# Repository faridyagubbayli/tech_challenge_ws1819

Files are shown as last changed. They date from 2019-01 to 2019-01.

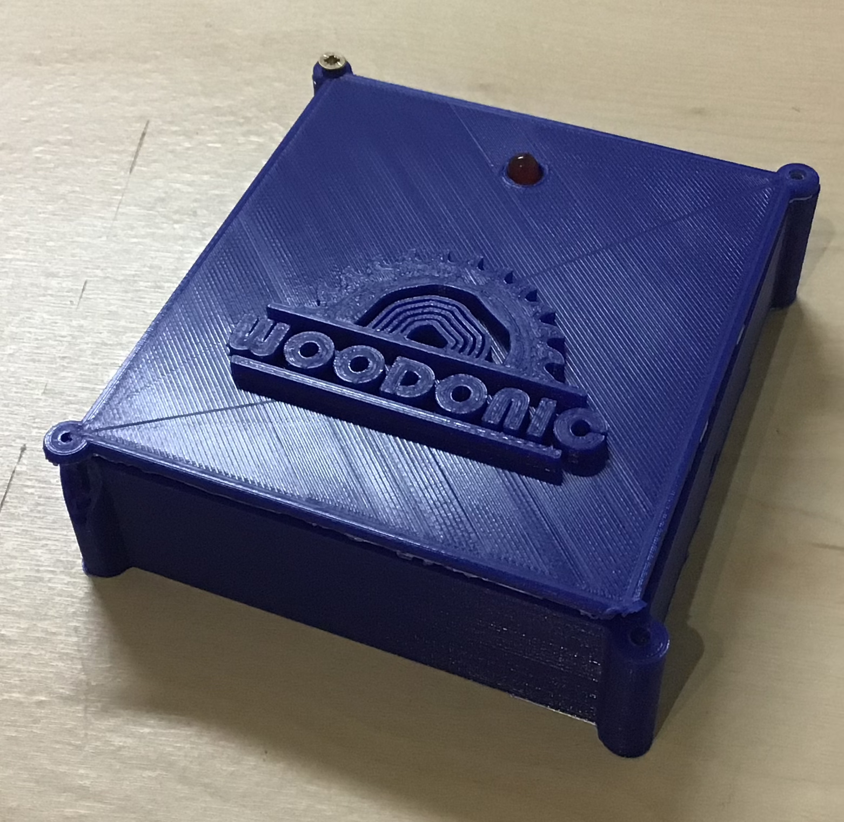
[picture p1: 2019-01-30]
IMG_0543.jpg

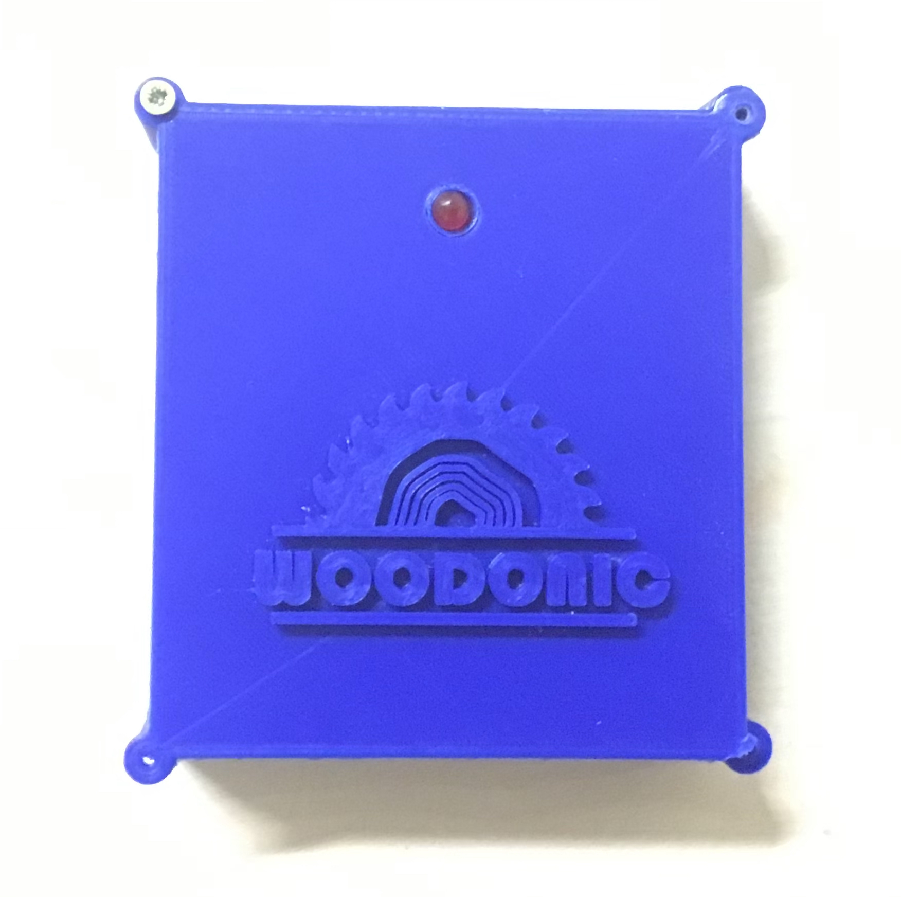
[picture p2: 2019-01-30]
IMG_3845.jpg

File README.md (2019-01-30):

# TUM Tech Challenge WS18_19 | Team AzTech - Woodonic | MakerSpace Challenge

This repository consists of following files:
- Unsupervised Audio Anomaly Detection with Gaussian Mixture Model  => Code for developing Machine Learning Solution
- Training ML for Raspberry PI.ipynb => Code for preparing Machine Learning Model for Raspberry Pi
- Raspberry_Pi_code.py => Code thats meant to be run inside Raspberry Pi, loads trained model and processes audio signals
- WOODONIC.pdf => Technical Documentation
- saved_models/ folder => Contains trained Machine Learning Folders

Additionally, you can find audio recording dataset and 3D design of the prototype in the following link (not uploaded here due to GitHub filesize limits):

https://drive.google.com/drive/folders/1RtNK6KFaf1NV8bzQA8amQgyWZAyrzATF?usp=sharing

Note that these dataset is required for running the code. Please download it to the main directory of the project such that all three folders stay at the main directory.

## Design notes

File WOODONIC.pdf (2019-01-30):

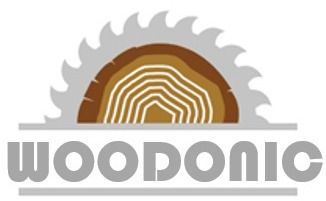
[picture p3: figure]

# Technical Documentation

## WOODONIC is a device that detects abnormal sounds in the cutting process of a table

saw and warns users with the notification light to stop the process.

# Hardware Components

Raspberry Pi Zero | x1

## Used for processing input audio signals and running trained Machine

Learning Model in order to predict anomalies.

16 GB MicroSD card | x1

## Used to install Raspbian OS on the Raspberry Pi Zero and store the solution code

USB mini microphone | x1

## Used for capturing audio input

MPU 6050 Accelerometer and Gyroscope sensor | x1

## Used to predict whether machine is working or not. Takes role in

Power Saving feature.

Light Emitting Diode | x1
User is notified by LED blink.
L7805 9V to 5V Voltage Regulator | x1

## Used to downgrade voltage from power source to be compatible with Raspberry Pi

## Woodonic by AzTech | Tech Challenge WS1819 | MakerSpace

# Software apps and Services

## Jupyter Notebooks Used while developing software solution in PC

## Raspbian OS Used to power up Raspberry PI Zero

## Scikit Sklearn Machine Learning Part is implemented using this Python Library

# Connecting Hardware Parts

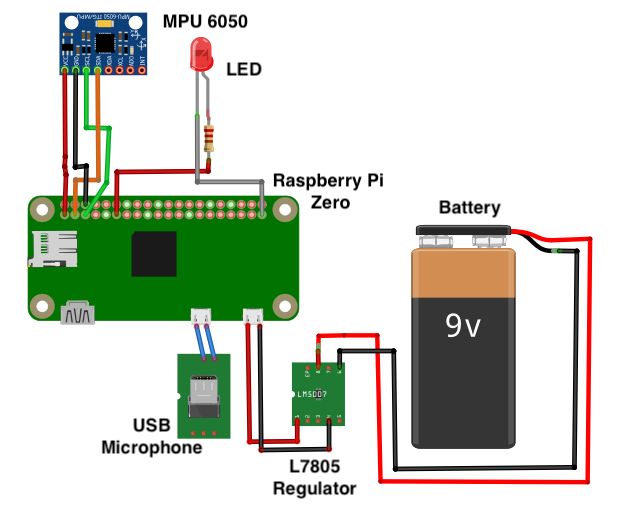
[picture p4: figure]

## - Connect LED to Raspberry PI by connecting Anode leg into GPIO 17 and Cathode into GND pin of Raspberry PI - Connect MPU6050 by connecting SDA, SCL, VCC and GND pins into corresponding

pins of Raspberry PI. VCC of MPU6050 should be connected 5V output of Raspberry PI.

## Note that other pins on MPU6050 will be free and not connected - Connect USB Microphone, via “USB to MicroUSB”, converter into Raspberry PI. Note that, despite there are 2 Micro USB ports available, only one of them can be used for

data transfer. Other one is usable for power purposes.

## - Insert SD Card into Raspberry PI

# Preparing Embedded Device

## In order to use Raspberry PI we need to install Raspbian OS. Of course, there exist other

distributions as well but for our purposes Raspbian OS is pretty much suitable. Follow below

## instructions: - Go to Raspberry PI website and navigate to download section - Download full version of Raspbian OS - Download USB Flash Imaging tool - Etcher - Connect Micro SD card to PC - Open Etcher, select previously downloaded image and Micro SD card and flash

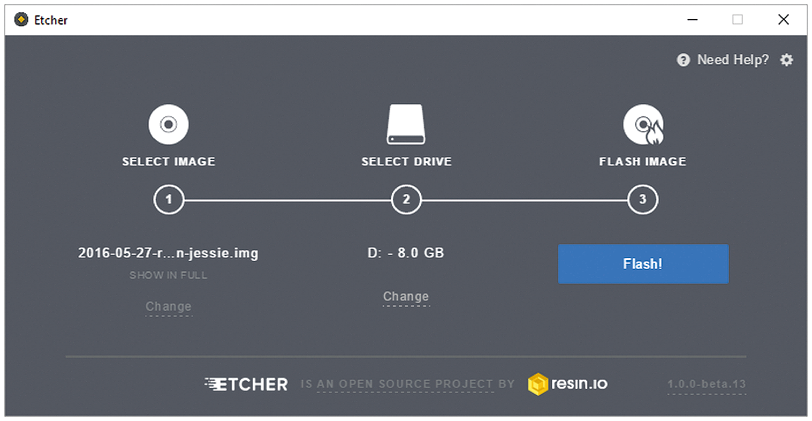
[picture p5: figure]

## - Once flashing finishes, navigate to Micro SD card using File Explorer - Specify your WiFi credentials in the file ‘etc/network/interfaces’

- Create an empty file and rename it to ‘ssh’. File should not have any extensions. Its required due to security reasons - Power up Raspberry PI - Connect to it using ‘ssh’. In Linux and Mac OS you can open terminal and type ‘ssh pi@ip_addr_of_rpi’ - When you’re asked about password, type ‘raspberry’. Its default password

At this step you should’ve installed Raspbian OS and successfully logged in. Next we need to configure Microphone.

## - Connect to Raspberry PI using VNC - Navigate to Preferences => Audio Device Settings - Select ‘USB PnP Sound Device’ and click on ‘Select Controls’ - Make sure ‘Microphone’ checkbox is ticked - Adjust the microphone level to MAX - Save settings and reboot Raspberry PI

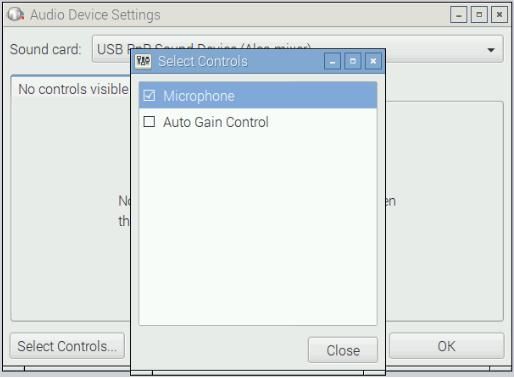
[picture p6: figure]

One last step in our embedded device configuration is the installation of required libraries. Open

## terminal in Raspberry PI and issue following commands one by one:

## sudo apt-get update sudo apt-get upgrade dpkg -l > ~/Desktop/packages.list pip freeze > ~/Desktop/pip-freeze-initial.list

sudo apt-get install xsel xclip libxml2-dev libxslt-dev python-lxml sudo apt-get install python-h5py python-numexpr python-dateutil python-six sudo apt-get install python-tz python-bs4 python-html5lib python-openpyxl sudo apt-get install python-tables python-xlrd python-xlwt cython sudo apt-get install python-sqlalchemy python-xlsxwriter sudo apt-get install python-jinja2 python-boto python-gflags sudo apt-get install python-googleapi python-httplib2 python-zmq sudo apt-get install libspatialindex-dev sudo pip install bottleneck rtree

## sudo apt-get install python-numpy python-matplotlib sudo apt-get install python-mpltoolkits.basemap python-pandas sudo apt-get install python-scipy python-sklearn python-statsmodels

## pip install librosa pip install scikit

# Preparing Dataset for Machine Learning

## During the project, team has visited MakerSpace and collected Audio Data for Machine Learning model. In total there was 4 hours of recording in a Wave format. Wave format was chosen to capture all insights of the data and to prevent any loss due to compression

algorithms. Additionally, noise cancellation features of recording devices were disabled.

## These data was divided into 2 parts. Normal sound consists of 3 and half hours and was

captured while target machine was working in idle, cutting, starting and stopping phases.

## Additionally background sound was also captured by generating different combinations of

working machines. Other part of data consists of abnormal sound and was just used for testing of the Machine Learning model.

Later this data was re-played into Raspberry PI and recorded again by Raspberry PI in order to

## get audio record through microphone attached to it. Last captured data was used to train

another Machine Learning model which was copied to Raspberry PI for predictions.

# Preparation of Machine Learning Model

Device makes predictions based on Gaussian Mixture Model and Isotonic Regression.

## Firstly, import necessary libraries and define constants:

import scipy
import scipy.fftpack
import numpy as np
from matplotlib import pyplot as plt import scipy.io.wavfile as wavfile from sklearn import svm
from sklearn import preprocessing import multiprocessing
from scipy.signal import welch from multiprocessing import Pool
from tqdm import tqdm_notebook
import time
from sklearn.preprocessing import StandardScaler import pickle
import librosa
from sklearn.externals import joblib

SAMPLE_RATE = 32000 #sampling rate of audio SEGMENT_TIME = 2 # in seconds, duration of each split

Next we define function to extract features from audio signal. This function heavily relies on Librosa Audio Processing library.

# Function to extract features from input signal(in our case Audio).

# Various features are extracted using Librosa and concatenated as a 1D Array def extract_feature(X):

sample_rate = SAMPLE_RATE

stft = np.abs(librosa.stft(X))
mfccs = np.mean(librosa.feature.mfcc(y=X, sr=sample_rate, n_mfcc=40).T,axis=0)
chroma = np.mean(librosa.feature.chroma_stft(S=stft, sr=sample_rate).T,axis=0)
mel = np.mean(librosa.feature.melspectrogram(X, sr=sample_rate).T,axis=0)
contrast = np.mean(librosa.feature.spectral_contrast(S=stft, sr=sample_rate).T,axis=0)
tonnetz = np.mean(librosa.feature.tonnetz(y=librosa.effects.harmonic(X), sr=sample_rate).T,axis=0) return np.hstack([mfccs,chroma,mel,contrast,tonnetz])

We also need some function to read files and convert them into Matrices for Machine Learning part.

# Function to read file, split into segments and retrieve features for each segment

def read_process_file(filename):
print("Processing file: ", filename)

# Read file into memory

signal, fs_rate = librosa.core.load(filename, SAMPLE_RATE) N = len(signal)
duration = int(SEGMENT_TIME * fs_rate)

# Split input signal into segments

signal = signal[: N - (N % duration)] samples = np.reshape(signal, (-1, duration))

# Process each segment to get features

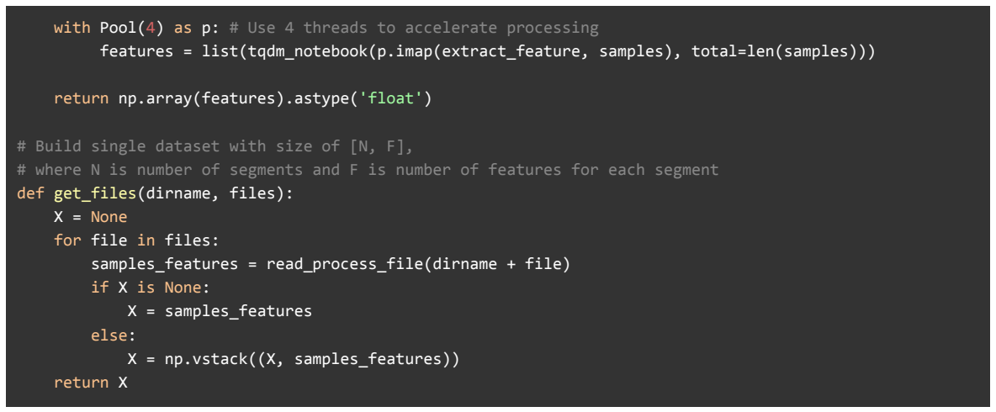
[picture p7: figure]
def get_files(dirname, files):; X = None; for file in files:; if X is None:; X = samples_features; else:; X = np.vstack((X, samples_features)); return X

with Pool(4) as p: # Use 4 threads to accelerate processing
features = list(tqdm_notebook(p.imap(extract_feature, samples), total=len(samples)))

return np.array(features).astype('float')

# Build single dataset with size of [N, F],

# where N is number of segments and F is number of features for each segment

samples_features = read_process_file(dirname + file)

Now we can read recorded normal and abnormal audio files and convert them into Training, Test and Validation datasets.

# Specify audio files with normal sound recording # Used for training, testing and validation normal_file_dir = 'records_from_pi/' normal_files = [

'normal_1.wav',
'normal_2.wav',
'normal_3.wav',
'normal_4.wav',
'normal_5.wav',
'silence_1.wav',
'silence_2.wav',
'silence_long.wav',
'silence_short.wav'
]

# Append label to each segment

X_normal = get_files(normal_file_dir, normal_files) normal_labels = np.ones((X_normal.shape[0], 1)) X_normal = np.hstack((X_normal, normal_labels))

# Specify audio files with abnormal sound recording # Used for testing and validation abnormal_file_dir = 'records_from_pi/' abnormal_files = [

'abnormal_1.wav',
'abnormal_2.wav',
]

# Append label to each segment

X_abnormal = get_files(abnormal_file_dir, abnormal_files) abnormal_labels = np.zeros((X_abnormal.shape[0], 1)) X_abnormal = np.hstack((X_abnormal, abnormal_labels))

# Show some output about data

print("Normal data shape: ", X_normal.shape) print("Abnormal data shape: ", X_abnormal.shape)

# Split normal data, get training dataset

train_mask = np.random.choice([False, True], len(X_normal), p=[0.40, 0.60]) X_train = X_normal[train_mask]
np.random.shuffle(X_train)
X_other = X_normal[~train_mask]

# Concatenate remaining normal data (on that's not used for training) and abnormal data X_other_abnormal = np.vstack((X_abnormal, X_other))

# Split concatenated data for validation and test, also shuffle data

other_abnormal_mask = np.random.choice([False, True], len(X_other_abnormal), p=[0.50, 0.50]) X_val = X_other_abnormal[other_abnormal_mask]
np.random.shuffle(X_val)
X_test = X_other_abnormal[~other_abnormal_mask]
np.random.shuffle(X_test)

# Separate labels from segment features label_index = 193

Y_train = X_train[:, label_index] X_train = X_train[:, 0:label_index]

Y_val = X_val[:, label_index] X_val = X_val[:, 0:label_index]

Y_test = X_test[:, label_index] X_test = X_test[:, 0:label_index]

# Show some output about data

print("Train data shape: ", X_train.shape) print("Train labels shape: ", Y_train.shape) print("Validation data shape: ", X_val.shape) print("Validation labels shape: ", Y_val.shape) print("Test data shape: ", X_test.shape) print("Test labels shape: ", Y_test.shape)

## At this point data is ready for Machine Learning model. We can build the model and fit to

training dataset. Don’t forget to apply Standard Scaler to the input on the runtime also. It ensures normalization and contributes to numerical stability.

# Apply standard scaler to data

ss = StandardScaler()
ss.fit(X_train)
X_train = ss.transform(X_train) X_val = ss.transform(X_val)
X_test = ss.transform(X_test)

# Also assuming that resnet feature generation is done from sklearn.mixture import GaussianMixture

from sklearn.isotonic import IsotonicRegression

# Build Gaussian Mixture Model and fit to training set

gmm_clf = GaussianMixture(covariance_type='spherical', n_components=4, max_iter=int(1e7)) # Obtained

via grid search
gmm_clf.fit(X_train)
log_probs_val = gmm_clf.score_samples(X_val)
# Also build Isotonic Regression for predictions

isotonic_regressor = IsotonicRegression(out_of_bounds='clip')
isotonic_regressor.fit(log_probs_val, Y_val) # y_val is for labels 0 - not food 1 - food (validation set)

# Obtaining results on the validation set

log_probs_val = gmm_clf.score_samples(X_val)
val_probabilities = isotonic_regressor.predict(log_probs_val) val_predictions = [1 if prob >= 0.5 else 0 for prob in val_probabilities]

# Calculate accuracy metrics

val_correct_pred = np.equal(Y_val, val_predictions)
val_acc = np.sum(val_correct_pred) / val_correct_pred.shape[0] print("Validation accuracy: ", val_acc)

# Obtaining results on the test set

log_probs_test = gmm_clf.score_samples(X_test)
test_probabilities = isotonic_regressor.predict(log_probs_test) test_predictions = [1 if prob >= 0.5 else 0 for prob in test_probabilities]

# Calculate accuracy metrics

test_correct_pred = np.equal(Y_test, test_predictions)
test_acc = np.sum(test_correct_pred) / test_correct_pred.shape[0] print("Test accuracy: ", test_acc)

Now we have our model and performance metrics. As a last step Scaler, Model and Regression should be saved and copied into Raspberry PI.

# Save model

save_dirname = "saved_models/"
joblib.dump(ss, save_dirname + "ss.pkl", compress=9)
joblib.dump(gmm_clf, save_dirname + "gmm_clf.pkl", compress=9) joblib.dump(isotonic_regressor, save_dirname + "isotonic_regressor.pkl", compress=9)

print("Your models are saved, please copy them into Raspberry PI")

# Embedded Device side code

## The code for Raspberry PI is somehow similar to the code above with some additions like

hardware output control. This is due to cross platform compatibility of Python programming language and support for Python and other libraries in the Raspberry PI side. As usual the code starts by importing necessary libraries, defining constants and setting up IO pin for output mode.

import sklearn
import pickle
import subprocess
import os
import librosa
import numpy as np from sklearn.externals import joblib import RPi.GPIO as GPIO

# Define Constants

SAMPLE_RATE = 32000
SEGMENT_TIME = 2
RECORD_TIME = 2

# Setup LED Output pin

ledpin = 17
GPIO.setmode(GPIO.BCM)
GPIO.setup(ledpin, GPIO.OUT, initial=GPIO.LOW)

Next some helper functions are defined. This functions are very similar the ones above as we follow the same feature extraction process for compatibility between inputs.

# Helper functions

def extract_feature(X):
sample_rate = SAMPLE_RATE
stft = np.abs(librosa.stft(X))
mfccs = np.mean(librosa.feature.mfcc(y=X, sr=sample_rate, n_mfcc=40).T,axis=0)
chroma = np.mean(librosa.feature.chroma_stft(S=stft, sr=sample_rate).T,axis=0)
mel = np.mean(librosa.feature.melspectrogram(X, sr=sample_rate).T,axis=0)
contrast = np.mean(librosa.feature.spectral_contrast(S=stft, sr=sample_rate).T,axis=0)
tonnetz = np.mean(librosa.feature.tonnetz(y=librosa.effects.harmonic(X), sr=sample_rate).T,axis=0) return np.hstack([mfccs,chroma,mel,contrast,tonnetz])

# Read and process recorded file

def read_process_file():
signal, fs_rate = librosa.core.load("temp.wav", SAMPLE_RATE) N = len(signal)

duration = int(SEGMENT_TIME * fs_rate)

signal = signal[: N - (N % duration)] samples = np.reshape(signal, (-1, duration)) features = extract_feature(samples[0, :])

return np.array(features).astype('float')

## One last thing before the main processing starts, we need to load Input Scaler, Gaussian Mixture Model and Isotonic Regression. These files were prepared using more powerful

machine, like PC, and copied to Raspberry PI.

# Load Standard Scaler, Gaussian Mixture Model and Isotonic Regression

ss = joblib.load('saved_models/ss.pkl')
gmm_clf = joblib.load('saved_models/gmm_clf.pkl')
isotonic_regressor = joblib.load('saved_models/isotonic_regressor.pkl') print("Models loaded successfully")

## Now we are ready for the main logic. Everytime we call another process in the Linux OS to

record audio for us. This audio is processed in order to get features which are feed into Machine Learning model. Finally, the model will output a prediction whether the audio signal is normal or abnormal. Based on this prediction, user will be notified by LED light.

while True: # loop forever
# Record audio to 'temp.wav'

subprocess.run(['arecord', '-D', 'hw:1', '-f', 'S16_LE', '-c1', '-r44100', '-d', str(RECORD_TIME), 'temp.wav'])

# Extract features from recorded audio

features = read_process_file()

# Scale features in order to normalize and prevent numerical stability issues scaled_features = ss.transform(features.reshape(1, -1))

log_probs = gmm_clf.score_samples(scaled_features)
probabilities = isotonic_regressor.predict(log_probs) predictions = [1 if prob >= 0.5 else 0 for prob in probabilities]

if predictions[0] == 0: # anomaly detected, turn on LED GPIO.output(ledpin, GPIO.HIGH)
else: # normal workflow, turn off LED GPIO.output(ledpin, GPIO.LOW)

GPIO.output(ledpin, GPIO.LOW)

# Images of final prototype

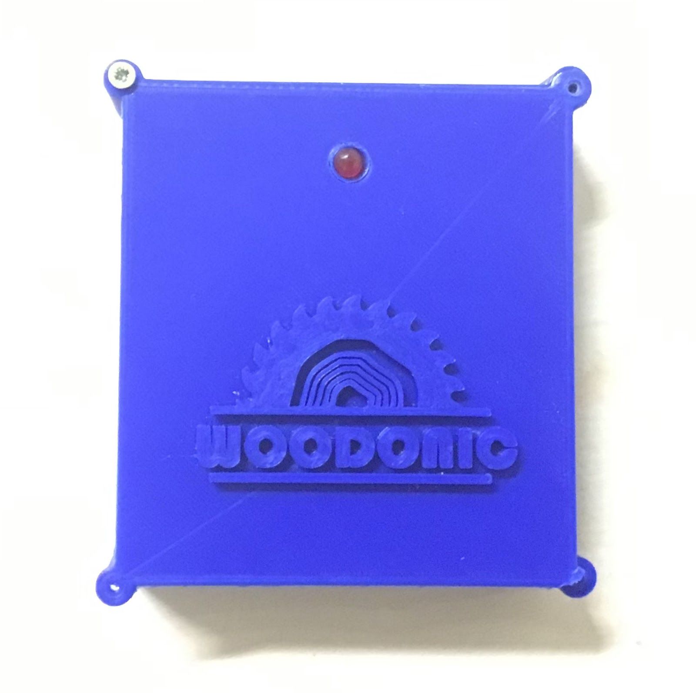
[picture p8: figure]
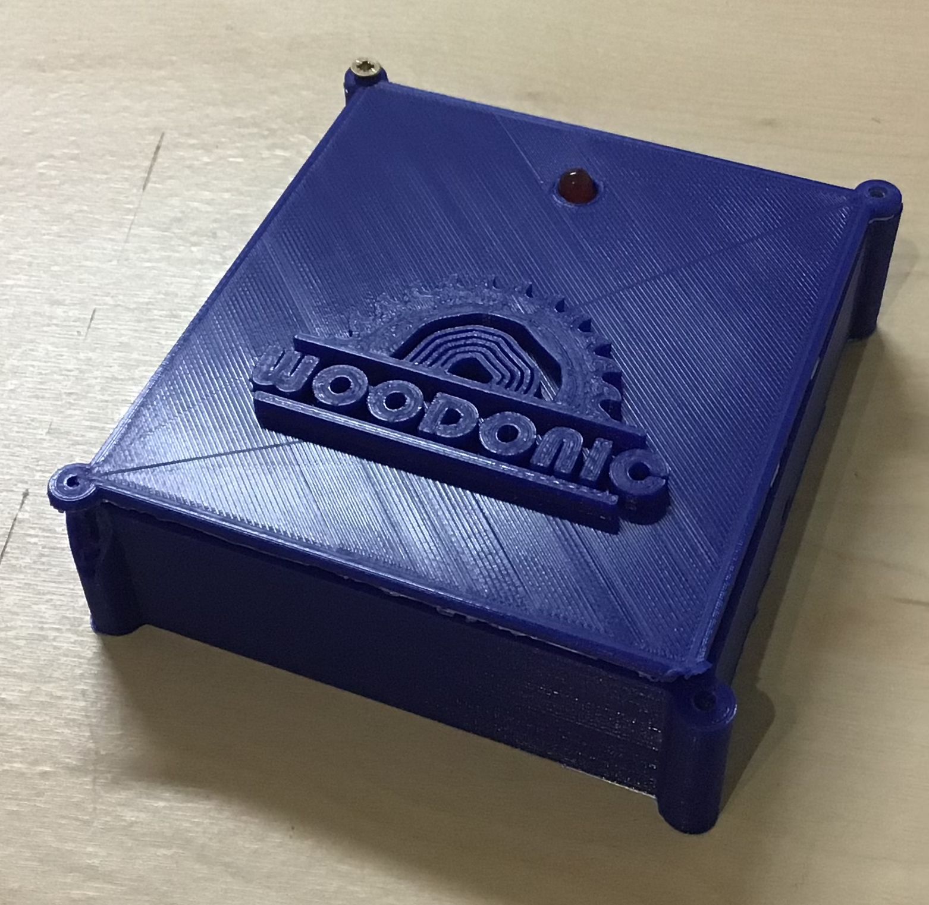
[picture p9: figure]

# Source code, Audio Recording Dataset and 3D Design files

## Source code, audio recordings of machines that were used for training above model and 3D design of Woodonic can be accessed via following GitHub link:

# https://github.com/faridyagubbayli/tech_challenge_ws1819
